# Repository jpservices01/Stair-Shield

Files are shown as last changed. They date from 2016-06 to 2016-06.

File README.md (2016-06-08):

# Stair-Shield
Project to control the LEDs in a staircase using a Arduino Mega 2560 and the shield uploaded here
The idea is to use a shift register to control the Leds independently so that there is not too much power drawn to the Mega 2560 controller. The shift register output intensity is controlled by one resistor and a PWM output.

There are actually one control per stairs with 15 Leds per stairs.

Used Kicad version 4.0.1
Used PCBNew 4.0.1

On PCB version 1.0
Had initially vias set to 0.6 mm with a drill of 0.4mm. PCB Tools said that rest material should be at least 0.15mm and therefore increased vias to 0.7mm with the same drill.

PCB Version 1.1
Corrected the above and remove vias from texts. Also changed the design rules to have at least vias of 0.7mm

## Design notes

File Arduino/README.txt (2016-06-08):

Files for the software development on the Arduino SDK

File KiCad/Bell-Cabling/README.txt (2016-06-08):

Files for the schematics of the cabling of to the bell

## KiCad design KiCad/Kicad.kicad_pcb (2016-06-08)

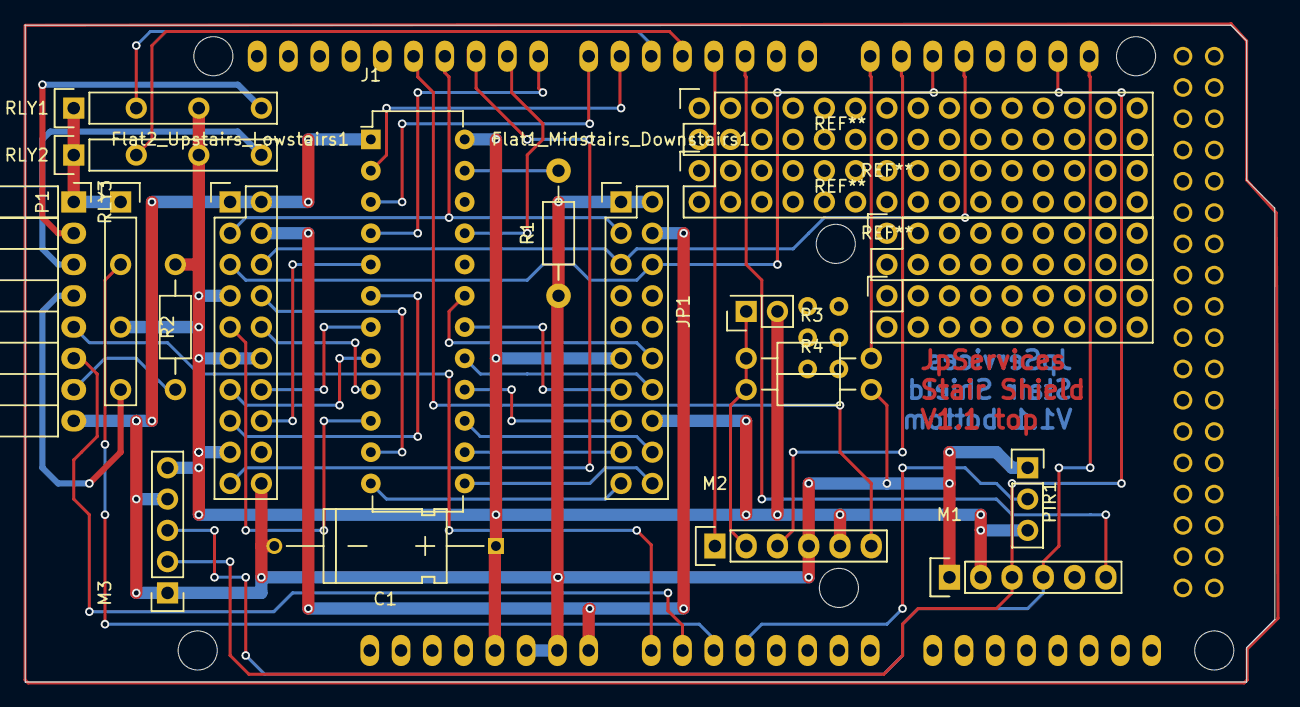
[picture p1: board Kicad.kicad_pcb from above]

Board: 2 copper layers, 101.5 x 53.3 mm, 18 parts (0 on the bottom side), 46 nets.

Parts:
C1: CP1; C_Axial_D6_L11_P18
Flat1_Midstairs_Downstairs1, Flat2_Upstairs_Lowstairs1: CONN_02X10; Pin_Header_Straight_2x10
J1: DM13A; DIP-24_W7.62mm
JP1: JUMPER; Socket_Strip_Straight_2x01
LED_Master_2nd_Floor1: ARDUINO_MEGA_SHIELD
M1: RTC3231
M2: HC-05; HC05
M3: BH1750FVI
P1: CONN_01X08; Socket_Strip_Angled_1x08
PIR1: PIR_Motion_Sensor; HC-SR505
R1: 270; Resistor_Horizontal_RM10mm
R2: R; Resistor_Horizontal_RM10mm
R3: 1K; Resistor_Horizontal_RM10mm
R4: 2K; Resistor_Horizontal_RM10mm
RLY1, RLY2, RLY3: RELAY_SIP_1A05; Socket_Strip_Straight_1x07_5.08

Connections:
+5V: C1.1, Flat1_Midstairs_Downstairs1.11, Flat1_Midstairs_Downstairs1.16, Flat2_Upstairs_Lowstairs1.7, Flat2_Upstairs_Lowstairs1.11, Flat2_Upstairs_Lowstairs1.12, Flat2_Upstairs_Lowstairs1.17, J1.24, JP1.2, LED_Master_2nd_Floor1.5V, M1.2, M2.5, M3.5, PIR1.3, R2.1, RLY1.5, RLY2.5, RLY3.5
/Bell Control/BellDownOn: LED_Master_2nd_Floor1.5, RLY1.3
/Bell Control/BellUpOn: LED_Master_2nd_Floor1.4, RLY2.3
/Bell Control/DoorStrikeOn: LED_Master_2nd_Floor1.AD2, RLY3.3
/Bell Control/RingDown: LED_Master_2nd_Floor1.AD0, P1.5
/Bell Control/RingUp: LED_Master_2nd_Floor1.AD1, P1.6
GND: C1.2, Flat1_Midstairs_Downstairs1.1, Flat1_Midstairs_Downstairs1.2, Flat2_Upstairs_Lowstairs1.1, Flat2_Upstairs_Lowstairs1.2, Flat2_Upstairs_Lowstairs1.20, J1.1, LED_Master_2nd_Floor1.GND1, LED_Master_2nd_Floor1.GND2, M1.1, M2.4, M3.1, M3.4, P1.8, PIR1.1, R1.1, R4.2
unnamed: Flat1_Midstairs_Downstairs1.3, Flat2_Upstairs_Lowstairs1.3, LED_Master_2nd_Floor1.11
unnamed: Flat1_Midstairs_Downstairs1.4, Flat2_Upstairs_Lowstairs1.4, LED_Master_2nd_Floor1.V_IN
unnamed: Flat1_Midstairs_Downstairs1.5, Flat2_Upstairs_Lowstairs1.6, LED_Master_2nd_Floor1.17
unnamed: Flat1_Midstairs_Downstairs1.6, Flat2_Upstairs_Lowstairs1.5, LED_Master_2nd_Floor1.16
unnamed: Flat1_Midstairs_Downstairs1.12, J1.19
unnamed: Flat1_Midstairs_Downstairs1.13, J1.18
unnamed: Flat1_Midstairs_Downstairs1.14, J1.17
unnamed: Flat1_Midstairs_Downstairs1.15, J1.16
unnamed: Flat1_Midstairs_Downstairs1.17, J1.14
unnamed: Flat1_Midstairs_Downstairs1.18, J1.15
unnamed: Flat1_Midstairs_Downstairs1.19, J1.12
unnamed: Flat1_Midstairs_Downstairs1.20, J1.13
unnamed: Flat2_Upstairs_Lowstairs1.8, J1.11
unnamed: Flat2_Upstairs_Lowstairs1.9, J1.10
unnamed: Flat2_Upstairs_Lowstairs1.10, J1.9
unnamed: Flat2_Upstairs_Lowstairs1.13, J1.8
unnamed: Flat2_Upstairs_Lowstairs1.14, J1.7
unnamed: Flat2_Upstairs_Lowstairs1.15, J1.6
unnamed: Flat2_Upstairs_Lowstairs1.16, J1.5
unnamed: Flat2_Upstairs_Lowstairs1.19, LED_Master_2nd_Floor1.10
unnamed: J1.2, LED_Master_2nd_Floor1.6
unnamed: J1.3, LED_Master_2nd_Floor1.7
unnamed: J1.4, LED_Master_2nd_Floor1.8
unnamed: J1.21, LED_Master_2nd_Floor1.9
unnamed: J1.23, R1.2
unnamed: JP1.1, M2.2, R3.1, R4.1
unnamed: LED_Master_2nd_Floor1.2, M1.6
unnamed: LED_Master_2nd_Floor1.3, M2.1
unnamed: LED_Master_2nd_Floor1.12, M2.6
unnamed: LED_Master_2nd_Floor1.14, R3.2
unnamed: LED_Master_2nd_Floor1.15, M2.3
unnamed: LED_Master_2nd_Floor1.20, M1.3, M3.2
unnamed: LED_Master_2nd_Floor1.21, M1.4, M3.3
unnamed: LED_Master_2nd_Floor1.AD3, PIR1.2
unnamed: P1.1, RLY1.1, RLY2.1, RLY3.1
unnamed: P1.2, RLY1.7
unnamed: P1.3, RLY2.7
unnamed: P1.4, RLY3.7
unnamed: P1.7, R2.2

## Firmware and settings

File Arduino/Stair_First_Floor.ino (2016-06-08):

#include <TimerOne.h>
#include <TimerThree.h>


int DAI = 6;  // Serial input DM13A pin 2
int DCK = 7;  // Clock DM13A pin 3
int LAT = 8;  // Output latch DM13A pin 4
int EN = 9;   // Output enable (active low) DM13A pin 21


int feedSpeed = 100;    // speed at wich the leds will be rolled on
int dropSpeed = 200;    // speed at wich the leds will be rolled off

int brightness = 0;    // how bright the LED is
int fadeAmount = 1;    // how many points to fade the LED (ATTENTION cannot changed without checking the brightness control)
boolean fadeIn = false;   // when true then a fade in sequence is starting and runing until full fade in
                          // when switched to true to false then start a fade out sequence
int fadeInSpeed = 10000;  // speed at which the fadeIn /out will be performed (in micro seconds)

volatile int fadeCounter = 0;

byte motionUpStairs=10;
byte motionMidStairs=11;

boolean goingUp=false;


void pwmHandler(){
  fadeCounter = (fadeCounter + 1)%255;
  if (fadeCounter >= brightness)
  { 
    digitalWrite(EN,HIGH);
    }   
  else  
    {
    digitalWrite(EN,LOW);
  } 
}   

void brightnessControl()
  {
  noInterrupts();
  if (fadeIn)
    {
    brightness = brightness + fadeAmount;
    if (brightness > 255) brightness = 255;
    }
  else
    {
    brightness = brightness - fadeAmount;
    if (brightness < 0) brightness = 0;      
    }
  interrupts();
  // analogWrite(13,brightness);
  // analogWrite(13,0);
  } 

void clockReg()
  {
  digitalWrite(DCK,HIGH);
  digitalWrite(DCK,LOW);  
  }
  
void latchReg()
  {
  digitalWrite(LAT,HIGH);
  digitalWrite(LAT,LOW);  
  }

void writeReg (word val)
  {
  int i;
  word value;

  value = val;
  for (i=0;i<16;i++)
    {
    digitalWrite(DAI,value>32767);
    value = value << 1;
    clockReg();
    }
    latchReg();
  }

void feedDown (word nbLed)
  {
  int i;

  digitalWrite(DAI,HIGH);
  fadeIn = true;
  for (i=0;i<nbLed;i++)
    {
    clockReg();
    latchReg();
    delay(feedSpeed);
    if (i == 6)
      {
       delay(2000); // delay if light reached the half floor 
      }
    }
    
  }

void dropDown (word nbLed)
  {
  int i;

  digitalWrite(DAI,LOW);
  fadeIn = false;
  for (i=0;i<nbLed;i++)
    {
    clockReg();
    latchReg();
    delay(dropSpeed);
    }
    
  }


void feedUp (word nbLed)
  {
  int i;
  word val=0;
  fadeIn = true;
  for (i=nbLed-1;i>=0;i--)
    {
    val = val + round(pow(2,i));
    writeReg(val);
    delay(feedSpeed);
    if (i == 7)
      {
       delay(2000); // delay if light reached the half floor 
      }
    }
    
  }

void dropUp (word nbLed)
  {
  int i;
  word val=0;

  val = round(pow(2,nbLed))-1;
  fadeIn = false;
  for (i=nbLed-1;i>=0;i--)
    {
    val = val - round(pow(2,i));
    writeReg(val);
    delay(dropSpeed);
    }
    
  }


// the setup routine runs once when you press reset:
void setup() {
  // declare pin 9 to be an output:
  pinMode(13, OUTPUT);
  pinMode(DAI, OUTPUT);
  pinMode(DCK, OUTPUT);
  pinMode(LAT, OUTPUT);
  pinMode(EN, OUTPUT);
  digitalWrite(DAI,LOW);  
  digitalWrite(DCK,LOW);  
  digitalWrite(LAT,LOW);  
  digitalWrite(EN,LOW);  

  pinMode(motionUpStairs,INPUT);
  pinMode(motionMidStairs,INPUT);
   
  Serial.begin(9600);
  Timer1.initialize(50);         // initialize timer1 to handle the software PWM
  Timer1.attachInterrupt(pwmHandler);  // attaches callback() as a timer overflow interrupt
  Timer3.initialize(fadeInSpeed);         // initialize timer3 to handle the feed in/out speed of leds
  Timer3.attachInterrupt(brightnessControl);  // attaches callback() as a timer overflow interrupt
}

// the loop routine runs over and over again forever:
void loop() {
  int val = 1;
  int i=0;
  int j=0;
  
  Serial.println("Start...");
  
  writeReg(0);
  delay(1000);
  writeReg(1);
  fadeIn=true;
  delay(1000);
  writeReg(2);
  delay(1000);
  writeReg(4);
  delay(1000);
  writeReg(8);
  delay(1000);
  writeReg(128);
  delay(1000);
  fadeIn=false;
  delay(5000);
  writeReg(0);
  delay(1000);
  feedUp(15);
  delay(1000);
  dropDown(15);
  delay(1000);
  writeReg(0);
  while(1)
  {
    i = 0;
    j = 0;
    while ((i < 3) && (j < 3))
    {
      i = i + 1;
      j = j + 1;
      if (digitalRead(motionUpStairs) == 0)
        {
        i = 0;
        }
      if (digitalRead(motionMidStairs) == 0)
        {
        j= 0;
        }

      delay(10);
    }   
    analogWrite(13,120);
    goingUp = false;
    writeReg(0);
    if (i > (3-1))      
      {
      Serial.println("Turn on down");
      feedDown(15);
      } 
    else if (j > (3-1))
      {
      Serial.println("Turn on up");
      feedUp(15);
      goingUp = true;
      } 
    delay(10000);
    // wait for motion detector to reset
    i = 0;
    while (i < 5)
    {
      i = i + 1;
      if ((digitalRead(motionUpStairs) != 0) || (digitalRead(motionMidStairs) != 0))
        {
        i = 0;
        }
      delay(10);
    }
    if (goingUp)      
      {
      Serial.println("Turn off up");
      dropUp(15);
      } 
    else
      {
      Serial.println("Turn off down");
      dropDown(15);
      } 
    analogWrite(13,0);
  }
}

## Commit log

2016-06-08 Create README.txt
    Arduino files
2016-06-08 Add files via upload
    Kicad master file
2016-06-08 Add files via upload
    Kicad PCBnew PCB file
    [Kicad.kicad_pcb]
2016-06-08 Add files via upload
    Schematic of the Arduino shield
    [Kicad.sch]
2016-06-08 Create README.txt
    bell interface schematic
2016-06-08 Add files via upload
    Master kicad file
2016-06-08 Add files via upload
    Schematic
    [Bell Cabling.sch]
2016-06-08 Add files via upload
    Control software for Arduino for the first floor and the stair shield
